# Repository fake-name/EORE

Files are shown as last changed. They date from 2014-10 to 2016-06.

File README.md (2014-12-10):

EORE
====

Era of Reionization Experiment

This is the hardware designs for the RF and backend components of a radio-telescope intended to look at the heavily [red-shifted](http://en.wikipedia.org/wiki/Redshift) [21 CM hydrogen line](http://en.wikipedia.org/wiki/Reionization#21-cm_line).  

While the normal 21 cm line is ~1420 MHz, this experiment is targeting the 50-250 MHz spectrum, which is where the 21 cm line from the era of reionization has been red-shifted to. 

Current topology is to use a SignalHound [BB60C](https://www.signalhound.com/products/bb60c/) spectrum analyser for the backend receiver (though my [API wrapper](https://github.com/fake-name/pySignalHound)), while the boards in this repository are front-end amplifiers and various components for tracking local oscillator drift, antenna characterization and so forth.

RF System hardware API documentation is [here](http://fake-name.github.io/EORE/doc/)

The eventual system will involve a great many separate nodes spread around the globe, all acting as a large-scale array.

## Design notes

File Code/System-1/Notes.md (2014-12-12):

I began to ask this question about the scheduling system on StackExchange, and partway through the writeup, I basically realised I was discussing the differences between cooperative multitasking and pre-emptive multitasking.

Since a single thread failing will tank the whole process, I've decided on a cooperative approach. 

###Approaches for handling complex scheduling requirements in a system involving many separate processes?

I'm working on designing a scheduling system that has to manage some complex, partially synchronous control state across a system that has a great many independent processes (it's a radio-telescope data-acquisition system, actually).

Basically, it requires a number of modules be cycled through a number of distinct steps on a repeating basis. 

 - Acquiring data (~30 minutes):
    - There are multiple separate processes that handle stream processing and write data out to file
    - Runs in a chunked basis, in ~30 second spans, which are challenging to interrupt.
 - Hardware calibration (short)
 - Antenna calibrarion (also short)
 - Other assorted housekeeping (pointing, etc...).

The critical thing is that I have to interrupt the main acquisition to perform calibration, and I'm trying to determine what the best approach to use for the system topology is.

 - Bottom-up scheduling:
    - Processes manage their own internal state, and yield flow back to a simple global loop periodically.
    - Effectively cooperative multitasking
 - Top-down scheduling:
    - State is managed in a global

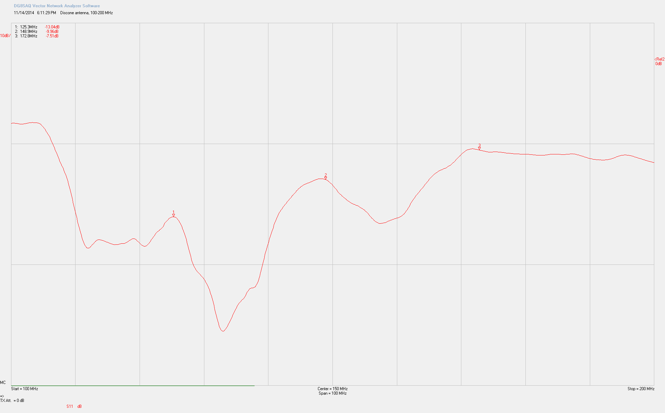
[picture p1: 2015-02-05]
Code/Prototypes/SWR Sweeper/SWR Sweep - Antenna - 100-200 Mhz, VNWA.png

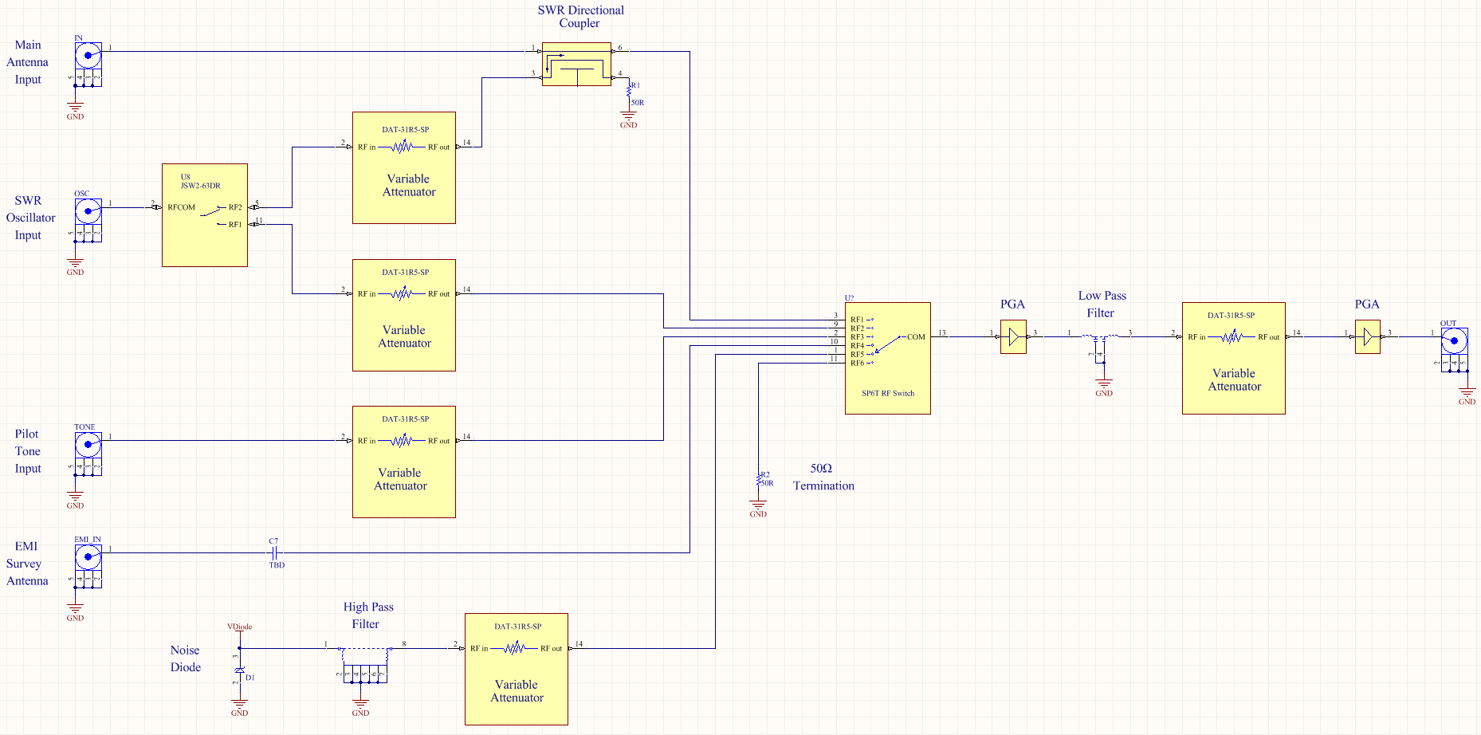
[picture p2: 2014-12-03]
PCBs/EORE R4 Diagram/EORE R4 Diagram.png

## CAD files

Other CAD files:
PCBs/Tigger RF Synthesizer & control module/RF Oscillator - R4/Rf Can 2.DWG
PCBs/Tigger RF Synthesizer & control module/RF Oscillator - R4/Rf Can 1.DWG
PCBs/Tigger RF Synthesizer & control module/RF Oscillator - R4/Draw1.SLDDRW

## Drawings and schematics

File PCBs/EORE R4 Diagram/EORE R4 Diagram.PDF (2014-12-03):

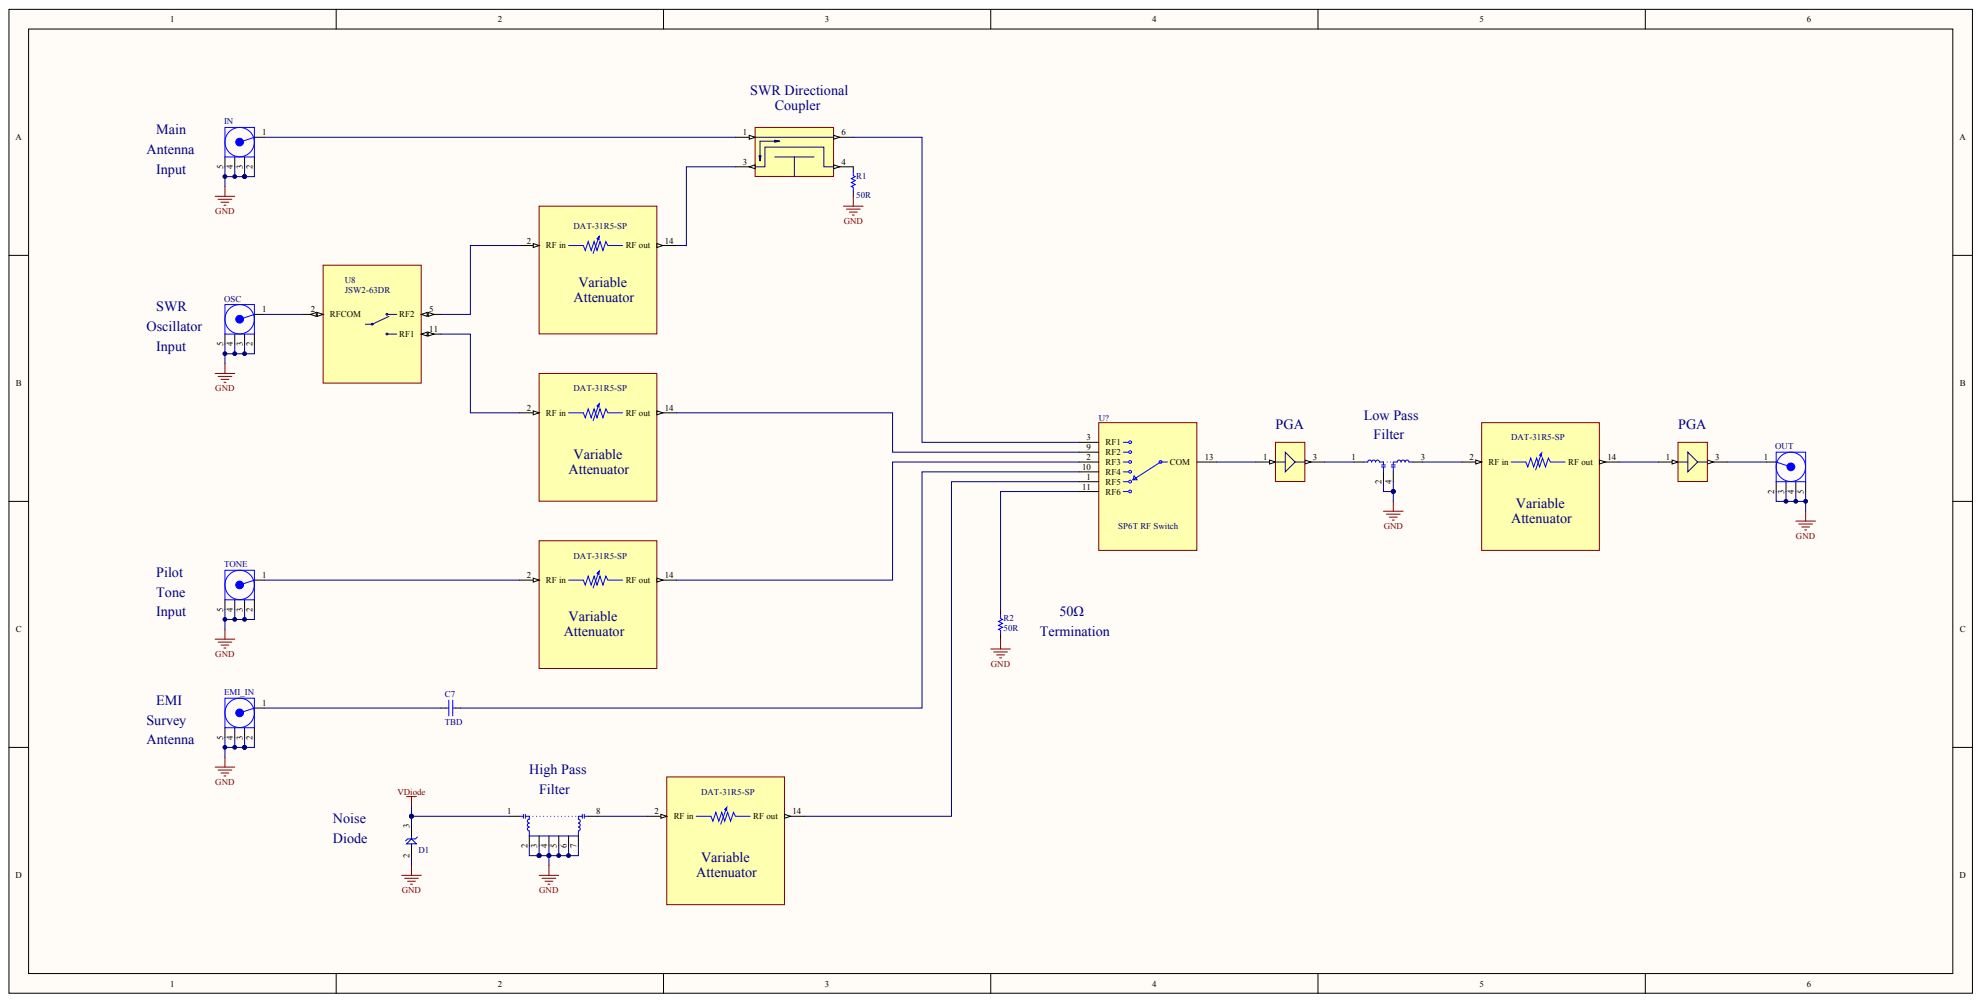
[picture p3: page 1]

RF3 2
RF4 10
RF5 1
RF6 11

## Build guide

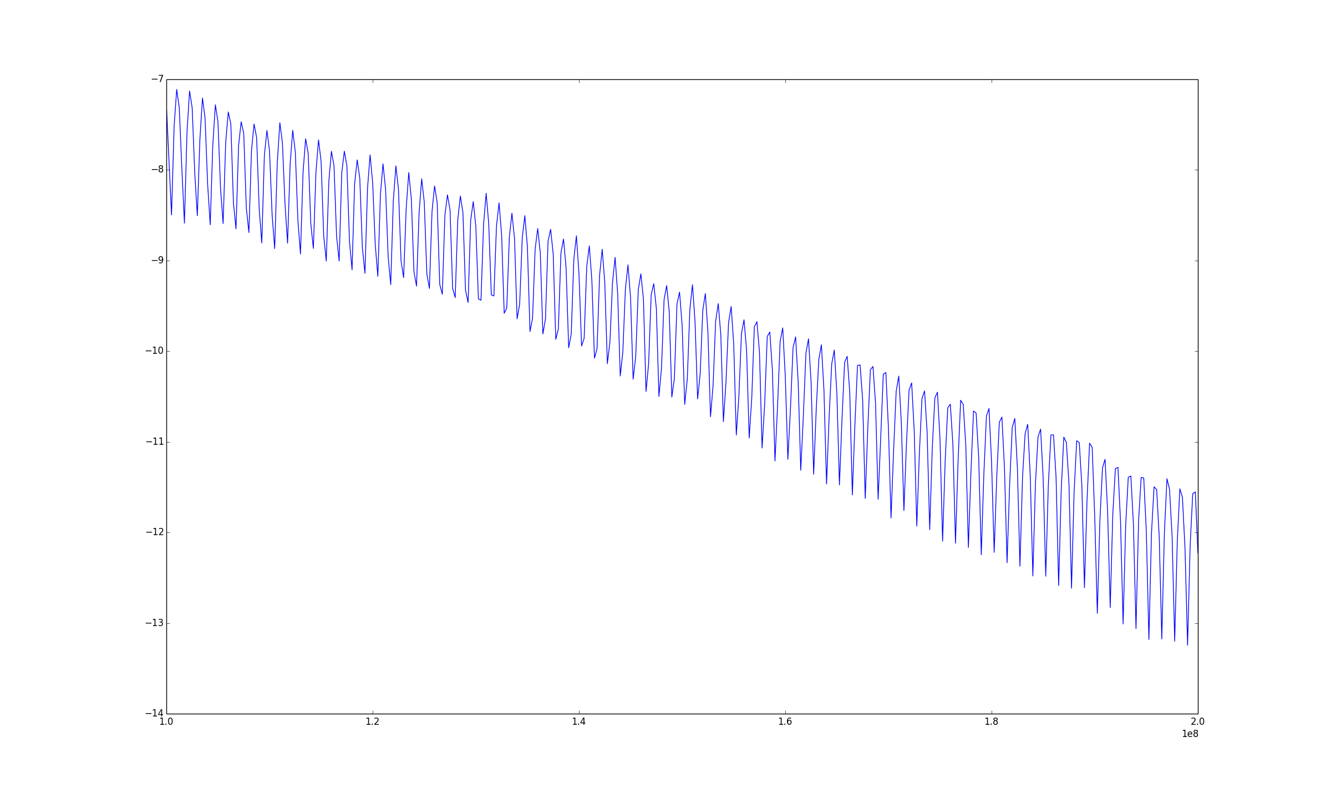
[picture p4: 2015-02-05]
Code/Prototypes/SWR Sweeper/SWR Sweep - Open input 100-200 Mhz, 250KHz steps.png

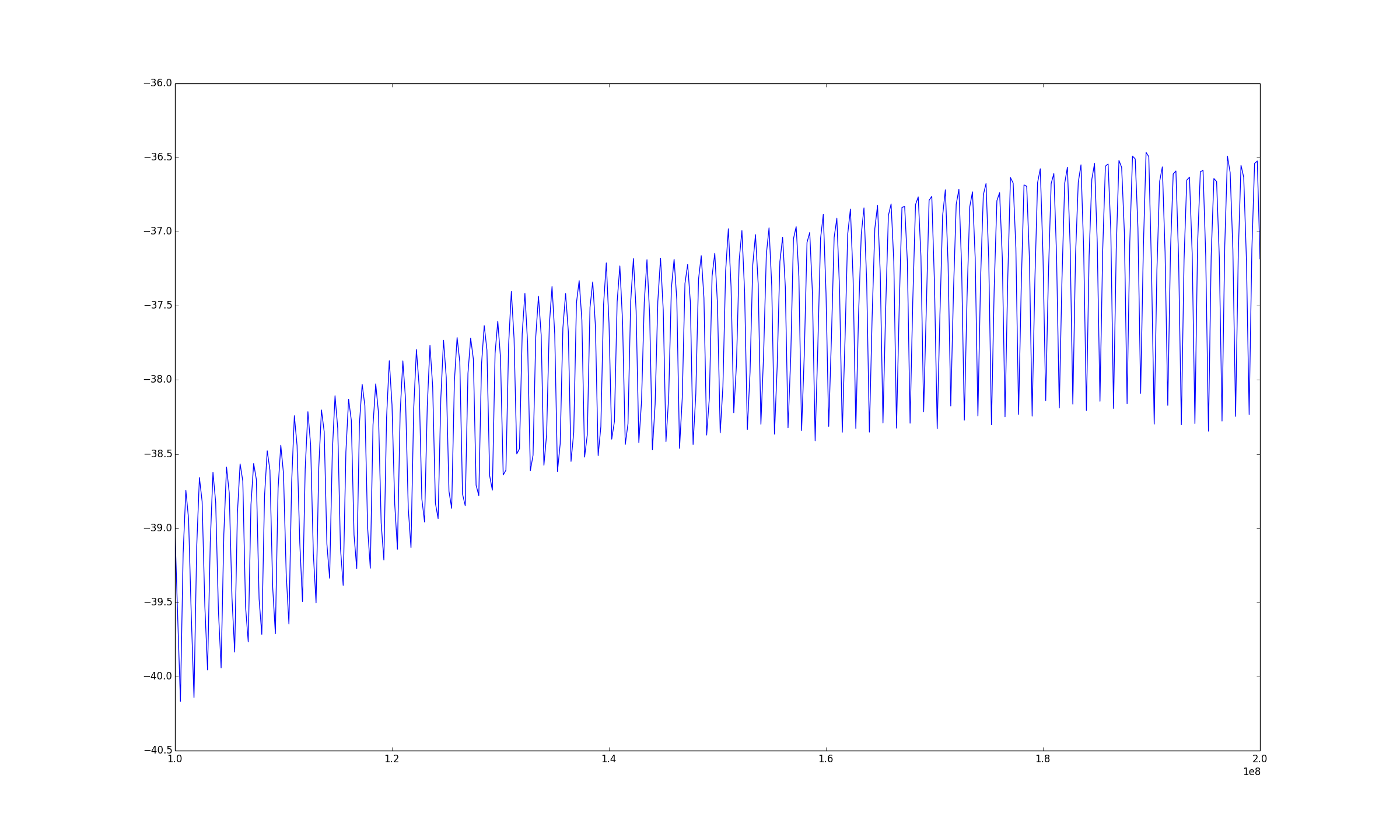
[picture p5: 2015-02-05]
Code/Prototypes/SWR Sweeper/SWR Sweep - Terminated input 100-200 Mhz, 250KHz steps.png

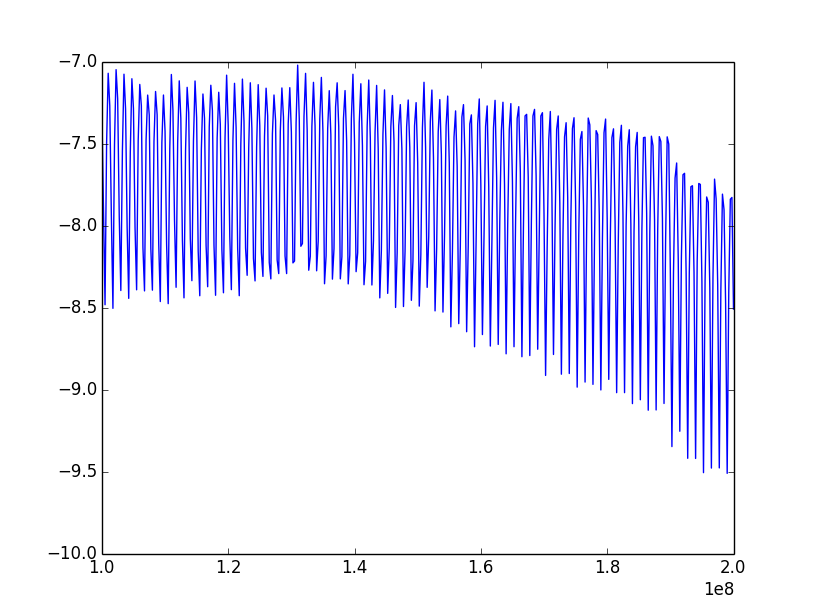
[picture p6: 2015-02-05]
Code/Prototypes/SWR Sweeper/SWR Sweep - Shorted input 100-200 Mhz, 250KHz steps.png

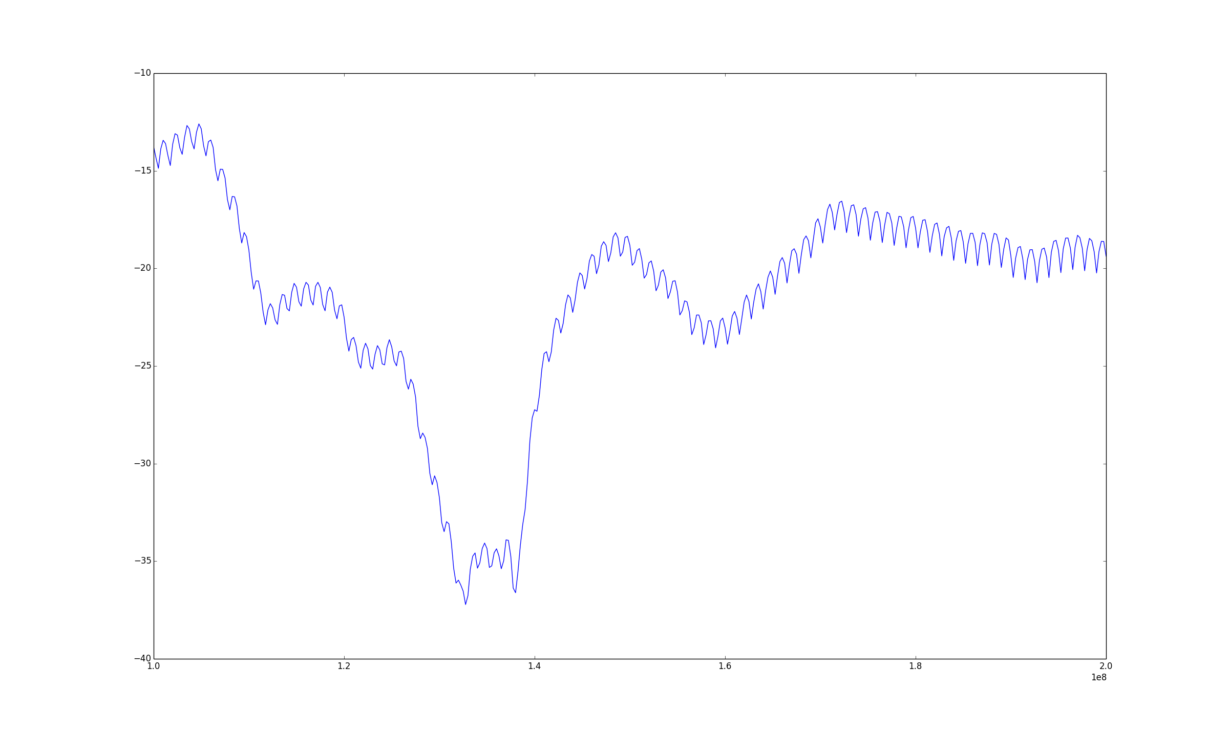
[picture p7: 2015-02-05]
Code/Prototypes/SWR Sweeper/SWR Sweep - Antenna - 100-200 Mhz, 250KHz steps.png

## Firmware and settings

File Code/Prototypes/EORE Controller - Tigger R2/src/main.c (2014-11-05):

/**
 * \file
 *
 * \brief Empty user application template
 *
 */

/**
 * \mainpage User Application template doxygen documentation
 *
 * \par Empty user application template
 *
 * Bare minimum empty user application template
 *
 * \par Content
 *
 * -# Include the ASF header files (through asf.h)
 * -# Minimal main function that starts with a call to board_init()
 * -# "Insert application code here" comment
 *
 */

/*
 * Include header files for all drivers that have been imported from
 * Atmel Software Framework (ASF).
 */
 #include <asf.h>
 #include <string.h>


#define DELAY_INTERVAL   250
#define TWI_SPEED        400000

void setup(void);
void send_led_command(uint8_t devAddr, uint8_t led, uint8_t brightness);


void setup(void)
{

	board_init();
	sysclk_init();
	ioport_init();
	wdt_disable(WDT);


	/* =============== UART1 =============== */ //(UART0 is defined but not UART1)
	#define PINS_DEVICE_TWI          (PIO_PA4A_TWCK0 | PIO_PA3A_TWD0)
	#define PINS_DEVICE_TWI_FLAGS    (PIO_PERIPH_A | PIO_DEFAULT)
	#define PINS_DEVICE_TWI_MASK     (PIO_PA4A_TWCK0 | PIO_PA3A_TWD0)
	#define PINS_DEVICE_TWI_PIO      PIOA
	#define PINS_DEVICE_TWI_ID       ID_PIOA
	#define PINS_DEVICE_TWI_TYPE     PIO_PERIPH_A
	#define PINS_DEVICE_TWI_ATTR     PIO_DEFAULT


	pio_configure_pin(PIO_PA3A_TWD0,  PIO_TYPE_PIO_PERIPH_A);
	pio_configure_pin(PIO_PA4A_TWCK0, PIO_TYPE_PIO_PERIPH_A);

	pio_configure(PINS_DEVICE_TWI_PIO, PINS_DEVICE_TWI_TYPE, PINS_DEVICE_TWI_MASK, PINS_DEVICE_TWI_ATTR);

	sysclk_enable_peripheral_clock(ID_TWI0);
	sysclk_enable_peripheral_clock(PINS_DEVICE_TWI_ID);
	sysclk_enable_peripheral_clock(ID_PIOB);


	twi_options_t conf;

	conf.master_clk = sysclk_get_cpu_hz();
	conf.speed = TWI_SPEED;
	conf.chip = 0;
	conf.smbus = 0;


	twi_master_init(DEVICE_TWI, &conf);

	ioport_set_pin_dir(LED_1, IOPORT_DIR_OUTPUT);
	ioport_set_pin_dir(LED_2, IOPORT_DIR_OUTPUT);
	ioport_set_pin_dir(LED_3, IOPORT_DIR_OUTPUT);
	ioport_set_pin_dir(LED_4, IOPORT_DIR_OUTPUT);

	// ioport_set_pin_level(LED_DRIVER_RESET, 1);
	// ioport_set_pin_dir(LED_DRIVER_RESET, IOPORT_DIR_OUTPUT);


	// // SoftI2CInit();
	// ioport_set_pin_level(LED_DRIVER_RESET, 0);
	// delay_ms(5);
	// ioport_set_pin_level(LED_DRIVER_RESET, 1);






}


void send_led_command(uint8_t devAddr, uint8_t led, uint8_t brightness)
{
	twi_packet_t packet;
	volatile uint8_t status;

	/* Data to send */
	packet.buffer = &brightness;
	/* Data length */
	packet.length = 1;
	/* Slave chip address */
	packet.chip = (uint32_t) devAddr >> 1;  // Device address must be >> by one, since apparently the driver injects the read/write flag internally
	/* Internal chip address */
	packet.addr[0] = led;
	packet.addr[1] = 0;
	packet.addr[2] = 0;
	/* Address length */
	packet.addr_length = 1;

	/* Perform a master write access */
	status = twi_master_write(TWI0, &packet);

	// if (status == TWI_SUCCESS)
	// {
	// 	ioport_toggle_pin_level(LED_6);
	// }
	// else
	// {
	// 	ioport_toggle_pin_level(LED_5);
	// }

}

int main (void)
{
	setup();

	uint8_t dir = 0;
	uint8_t brightness = 0;
	while (1)
	{



		// for (uint8_t led = 0; led < 16; led += 1)
		// {
		// 	send_led_command(DRV_1_ADDR, led, brightness);
		// 	send_led_command(DRV_2_ADDR, led, brightness);
		// 	send_led_command(DRV_3_ADDR, led, brightness);
		// 	send_led_command(DRV_4_ADDR, led, brightness);
		// }
		// // Spin
		// ioport_set_pin_level(LED_1, 1);
		// delay_ms(DELAY_INTERVAL);
		// ioport_set_pin_level(LED_1, 0);

		// if (brightness == 0xFF)
		// {
		// 	dir = 1;
		// }
		// else if (brightness == 0x00)
		// {
		// 	dir = 0;
		// }

		// if (dir == 0)
		// {
		// 	brightness += 1;
		// }
		// else if (dir == 1)
		// {
		// 	brightness -= 1;
		// }


		ioport_set_pin_level(LED_1, 1);
		delay_ms(DELAY_INTERVAL);
		ioport_set_pin_level(LED_1, 0);

		ioport_set_pin_level(LED_2, 1);
		delay_ms(DELAY_INTERVAL);
		ioport_set_pin_level(LED_2, 0);

		ioport_set_pin_level(LED_3, 1);
		delay_ms(DELAY_INTERVAL);
		ioport_set_pin_level(LED_3, 0);

		ioport_set_pin_level(LED_4, 1);
		delay_ms(DELAY_INTERVAL);
		ioport_set_pin_level(LED_4, 0);


	}
	// Insert application code here, after the board has been initialized.
}

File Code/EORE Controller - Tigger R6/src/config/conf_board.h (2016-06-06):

/**
 * \file
 *
 * \brief User board configuration template
 *
 */

#ifndef CONF_BOARD_H
#define CONF_BOARD_H

#define BOARD_FREQ_SLCK_XTAL 32768
#define BOARD_FREQ_SLCK_BYPASS BOARD_FREQ_SLCK_XTAL

#define BOARD_FREQ_MAINCK_XTAL 12000000
#define BOARD_FREQ_MAINCK_BYPASS BOARD_FREQ_MAINCK_XTAL

#define BOARD_OSC_STARTUP_US   15625


// Pin definitions
#define LED_1           IOPORT_CREATE_PIN(PIOA, 27)
#define LED_2           IOPORT_CREATE_PIN(PIOA, 11)
#define LED_3           IOPORT_CREATE_PIN(PIOA, 26)
#define LED_4           IOPORT_CREATE_PIN(PIOA, 12)

#define HEATER_ON       IOPORT_CREATE_PIN(PIOA, 2)

#define VCO_ON          IOPORT_CREATE_PIN(PIOA, 20)
//#define HEATER_OLD    IOPORT_CREATE_PIN(PIOA,  5)
#define OSC_EN          IOPORT_CREATE_PIN(PIOA,  9)
#define NOISE_DIODE_PS  IOPORT_CREATE_PIN(PIOB,  2)
#define VCO_SWEEPER_PS  IOPORT_CREATE_PIN(PIOA,  0)

#define CS_1            IOPORT_CREATE_PIN(PIOB,  3)
#define CS_2            IOPORT_CREATE_PIN(PIOA, 17)
#define CS_3            IOPORT_CREATE_PIN(PIOA, 18)
#define CS_4            IOPORT_CREATE_PIN(PIOA, 19)
#define CS_5            IOPORT_CREATE_PIN(PIOA, 16)
#define CS_6            IOPORT_CREATE_PIN(PIOA, 15)
#define CS_OSC_ATTEN    IOPORT_CREATE_PIN(PIOA, 10)   // also known as "CS7"
#define CS_SWEEP_ATTEN  IOPORT_CREATE_PIN(PIOA,  6)   // also known as "CS8"

//#define CS_SW           IOPORT_CREATE_PIN(PIOA, 18)

#define MOSI            IOPORT_CREATE_PIN(PIOA, 13)
#define SCK             IOPORT_CREATE_PIN(PIOA, 14)

//#define SWITCH_2        IOPORT_CREATE_PIN(PIOB, 1)
//#define SWITCH_3        IOPORT_CREATE_PIN(PIOB, 2)
//#define SWITCH_4        IOPORT_CREATE_PIN(PIOB, 3)

// SI57x TWI port.
#define DEVICE_SCL      IOPORT_CREATE_PIN(PIOA, 4)
#define DEVICE_SDA      IOPORT_CREATE_PIN(PIOA, 3)
#define DEVICE_TWI      TWI0

// Temperature sensors get their own TWI module.
#define TEMP_SENSOR_SCL      IOPORT_CREATE_PIN(PIOB, 1)
#define TEMP_SENSOR_SDA      IOPORT_CREATE_PIN(PIOB, 0)
#define TEMP_SENSOR_TWI      TWI2


#define DRV_1_ADDR  (0xA0 | 0 << 1)
#define DRV_2_ADDR  (0xA0 | 1 << 1)
#define DRV_3_ADDR  (0xA0 | 2 << 1)
#define DRV_4_ADDR  (0xA0 | 3 << 1)


/* =============== TWI1 =============== */
#define PINS_DEVICE_TWI          (PIO_PA4A_TWCK0 | PIO_PA3A_TWD0)
#define PINS_DEVICE_TWI_FLAGS    (PIO_PERIPH_A | PIO_DEFAULT)
#define PINS_DEVICE_TWI_MASK     (PIO_PA4A_TWCK0 | PIO_PA3A_TWD0)
#define PINS_DEVICE_TWI_PIO      PIOA
#define PINS_DEVICE_TWI_ID       ID_PIOA
#define PINS_DEVICE_TWI_TYPE     PIO_PERIPH_A
#define PINS_DEVICE_TWI_ATTR     PIO_DEFAULT


/* =============== Debug UART =============== */
#define DEBUG_UART                 (Usart*)UART3
#define DEBUG_UART_ID              ID_UART3
#define DEBUG_UART_BAUDRATE        115200
#define DEBUG_UART_MODE            UART_MR_PAR_NO
#define DEBUG_UART_CHAR_LENGTH     8
#define DEBUG_UART_PARITY          UART_MR_PAR_NO
#define DEBUG_UART_STOP_BIT        false

#define DEBUG_UART_PIN_TX         IOPORT_CREATE_PIN(PIOB, 11)
#define DEBUG_UART_PIN_RX         IOPORT_CREATE_PIN(PIOB, 10)

#define DEBUG_UART_IRQ            UART3_IRQn
#define DEBUG_UART_ISR_HANDLER    UART3_Handler



#endif // CONF_BOARD_H

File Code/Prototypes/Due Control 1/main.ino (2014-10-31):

#define SI570_DEBUG

#include <Wire.h>
#include <stdlib.h>
#include "Si570.h"

Si570 *vfo;


#define SW_1 		44
#define SW_2 		30
#define SW_3 		32

#define DATA 		34
#define LATCH_3 	36
#define CLK 		38
#define LATCH_2 	40
#define LATCH_1 	42

uint8_t pins[] = {30, 32, 34, 36, 38, 40, 42, 44};
uint8_t cnt;



#define PACKET_HEADER 0x5D
#define WRITE_ATTEN_1 0xAA
#define WRITE_ATTEN_2 0xAB
#define WRITE_ATTEN_3 0xAC
#define WRITE_SWITCH  0x0C
#define WRITE_FREQ    0xC0


typedef enum
{
	NO_PACKET,
	WAIT_COMMAND,

	WAIT_DATA_1,
	WAIT_DATA_2,
	WAIT_DATA_3,
	WAIT_DATA_4,
	WAIT_CHECKSUM,

	PACKET_VALID
} sysState;




typedef union UnionU32_t
{
	uint8_t  bytes[4];
	uint32_t value;
} unionU32_t;

typedef struct
{
	uint8_t command;
	unionU32_t value;
} command_packet;


volatile uint8_t checksum = 0;

volatile command_packet packet = {0, 0};
volatile sysState state = NO_PACKET;


#define _BV(bit) (1 << (bit))

void writeAtten(uint8_t which, uint8_t atten)
{
	uint8_t cs_pin;
	switch (which)
	{
		case 0:
			cs_pin = LATCH_1;
			break;
		case 1:
			cs_pin = LATCH_2;
			break;
		case 2:
			cs_pin = LATCH_3;
			break;
		default:
			return;
	}

	if (atten >= 64)
	{
		return;
	}

	for (uint8_t i = 0; i < 6; i += 1)
	{
		if (atten & _BV(5-i))
			digitalWrite(DATA, 1);
		else
			digitalWrite(DATA, 0);
		delayMicroseconds(2);
		digitalWrite(CLK, 1);
		delayMicroseconds(2);
		digitalWrite(CLK, 0);
		delayMicroseconds(2);


	}

	digitalWrite(DATA, 0);
	digitalWrite(cs_pin, 1);
	delayMicroseconds(2);
	digitalWrite(cs_pin, 0);



}

void writeSwitch(uint8_t val)
{
	// SO input 1 of the switch is the *MOST* significant bit. Wat?
	if (val & _BV(0))
		digitalWrite(SW_3, 1);
	else
		digitalWrite(SW_3, 0);

	if (val & _BV(1))
		digitalWrite(SW_2, 1);
	else
		digitalWrite(SW_2, 0);

	if (val & _BV(2))
		digitalWrite(SW_1, 1);
	else
		digitalWrite(SW_1, 0);

}







void process_packet(volatile command_packet *pkt)
{

	switch (pkt->command)
	{
		case WRITE_ATTEN_1:
			Serial.print("Atten Set 1 ");
			Serial.println(pkt->value.value);
			writeAtten(0, (uint8_t) pkt->value.value);
			break;

		case WRITE_ATTEN_2:
			Serial.print("Atten Set 2 ");
			Serial.println(pkt->value.value);
			writeAtten(1, (uint8_t) pkt->value.value);
			break;

		case WRITE_ATTEN_3:
			Serial.print("Atten Set 3 ");
			Serial.println(pkt->value.value);
			writeAtten(2, (uint8_t) pkt->value.value);
			break;


		case WRITE_SWITCH:
			Serial.print("Switch Set ");
			Serial.println(pkt->value.value);
			writeSwitch((uint8_t) pkt->value.value);
			break;

		case WRITE_FREQ:
			if (pkt->value.value < 10e6 | pkt->value.value > 810e6 )
			{
				Serial.print("ERROR: Invalid Frequency: ");
				Serial.println(pkt->value.value);
			}
			else
			{
				vfo->setFrequency(pkt->value.value);
				Serial.print("OK: Freq Set: ");
				Serial.println(pkt->value.value);
			}
			break;

		default:
			Serial.println("Error! Unknown command!");
			break;
	}


}


void parse(uint8_t dataByte)
{
	switch (state)
	{
		case NO_PACKET:
			if (dataByte == PACKET_HEADER)
			{
				state = WAIT_COMMAND;
				checksum += dataByte;
			}
			break;

		case WAIT_COMMAND:
			packet.command = dataByte;
			state = WAIT_DATA_1;
			checksum += dataByte;
			break;

		case WAIT_DATA_1:

			packet.value.bytes[0] = dataByte;
			state = WAIT_DATA_2;
			checksum += dataByte;
			break;
		case WAIT_DATA_2:

			packet.value.bytes[1] = dataByte;
			state = WAIT_DATA_3;
			checksum += dataByte;
			break;
		case WAIT_DATA_3:

			packet.value.bytes[2] = dataByte;
			state = WAIT_DATA_4;
			checksum += dataByte;
			break;
		case WAIT_DATA_4:

			packet.value.bytes[3] = dataByte;
			state = WAIT_CHECKSUM;
			checksum += dataByte;
			break;

		case WAIT_CHECKSUM:

			if (dataByte ==  checksum)
			{
				state = PACKET_VALID;
				process_packet(&packet);
			}
			else
			{
				Serial.println("Invalid checksum!");
				Serial.print("Should be ");
				Serial.print(checksum);
				Serial.print(" received ");
				Serial.println(dataByte);
			}
			// Falls through to default (intentionally)!
		default:
			Serial.print("Rx Complete");
			state = NO_PACKET;
			checksum = 0;
			break;
	}

}




void setup(){}


void loop()
{

	for (uint8_t x = 0; x < sizeof(pins); x += 1)
	{
		pinMode(pins[x], OUTPUT);
		digitalWrite(pins[x], 0);
	}

	Serial.begin(115200);


	Serial.println("Device init...");
	vfo = new Si570(SI570_I2C_ADDRESS, 56.320e6);

	if (vfo->status == SI570_ERROR) {
		// The Si570 is unreachable. Show an error for 3 seconds and continue.
		Serial.println("Si570 comm error");
		delay(3000);
	}


	// This will print some debugging info to the serial console.
	vfo->debugSi570();


	#define DELAY_TIME 200



	vfo->setFrequency(100E6);


	while(1)
	{
		if (Serial.available())
		{
			uint8_t ser = Serial.read();
			parse(ser);
		}
	}

}

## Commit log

2014-10-09 Initial push of sources from SVN.
    [Amplifier.SchDoc, Attenuator.SchDoc, Directional Coupler.SchDoc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]
2014-10-09 Adding test-board control sources.
2014-10-10 Ordered the R3/4 PCBs. Minor testing code stuff.
    [EORE Integrated System - R3.PrjPcb, Main.PcbDoc, RF Oscillator - R4.PrjPcb]
2014-10-14 Added the ability to control the SI570 over the serial interface. Also, the corresponding python wrapper for talking to the oscillator board.
    [Si570.cpp, control.py, outCon.ino]
2014-10-16 Aggregated control systems onto the due board.
2014-10-24 Next RF synthesizer board. This one has a mixer-based VCO driven sweep oscillator, for faster VSWR sweeps.
    [Attenuator.SchDoc, Main.PcbDoc, Main.SchDoc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]
2014-10-25 Initial prototype SWR sweeper.
2014-10-29 More work on the EORE boards.
    [Main.PcbDoc, Programming Interface and Power.SchDoc, RF Oscillator - R5.PrjPcb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]
2014-10-30 There's a bug somewhere in the Si570 library that is causing the output of the oscillator to be incorrect at ~200 Mhz. Arrrgh.
    [Si570.cpp, controlApi.py, takeSweeps.py]
2014-10-31 Fixed bizarre rounding bug in the Si570 control code. Fuck you ridiculously confusing code.
    [Si570.cpp, main.ino]
2014-10-31 Testing the Si570 output stability.
    [Si570.cpp, controlApi.py, siCalc.py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]
2014-10-31 Next EORE board rev.
    [Attenuator.SchDoc, EORE Integrated System - R4.PrjPcb, Main.PcbDoc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]
2014-11-05 did the assembly of the new EORE Eeyore and Tigger boards. Some updates/minor changes to the drawings from the assembly process.
    [Programming Interface and Power.SchDoc, RF Oscillator - R4.PrjPcb, USB Interface.SchDoc]
2014-11-05 Initial test-code for the EORE Tigger control board. It's mostly stolen from an earlier project. It just flashes some LEDs at this point, but that means all the board-init crap is working. Whooo?
2014-11-05 Ignore build files for the ARM stuff.
2014-11-06 Entirely switched project over to C++ so I can ~~steal~~ reuse arduino libraries. Got some basic printf functions working. Spent a while dicking about with header file.
2014-11-06 I2C reads are working, writing is a bit broken. Progress!
    [Main.PcbDoc]
2014-11-07 All peripherals now seem to work. At this point, the only things remaining are to implement the interrupt-driven serial rx buffer, and hook up the command parser. I have RX interrupts working, but ri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
    [Main.PcbDoc, Main.SchDoc, USB Interface.SchDoc]
2014-11-08 Controller is actually functional, parser is hooked up. There's some issues somewhere still, not sure if it's real or just idiocy in my testing practices for the amps.
    [EORE Integrated System - R4.PrjPcb, Main.PcbDoc, Main.SchDoc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]
2014-11-13 Improved footprints for the all the small SMT parts. Better silkscreen pin-1 markings, larger pads for the SP6T switch so it can hopefully be soldered and/or reflowed more easily in the future.
    [Main.PcbDoc]
2014-11-14 Board fixes.
    [EORE Integrated System - R2.PrjPcb, Main.PcbDoc, RF Oscillator - R4.PrjPcb]
2014-11-15 More work on SWR sweeper. Improvements on the EORE interface library. Updated readme.
    [Main.PcbDoc]
2014-11-15 Added high-pass filter to noise diode, which should (hopefully) remove the extremely high amplitude low-frequency output from the noise-diode, that is causing issues saturating the IF stage of the si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
    [Main.PcbDoc, Main.SchDoc, Noise Diode.SchDoc]
2014-11-19 Wound up editing the wrong board (I was updating the R3 board files, not the R4 version. Swapped the files around to fix.
    [EORE Integrated System - R3.PrjPcb, EORE Integrated System - R4.PrjPcb, Main.PcbDoc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]
2014-11-20 New board ordering.
    [EORE Integrated System - R4.PrjPcb, Main.PcbDoc, Main.SchDoc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]
2014-11-21 Temp sensing now works on the Tigger controller board.
    [RF Oscillator - R5.PrjPcb]
2014-11-22 PWM output now works, and is tested. Cleaned up the code structure a bit too.
    [Main.PcbDoc, USB Interface.SchDoc]
2014-11-25 Thermal regulator now thermally regulates. PID loop will need tuning for the eventual system's thermal characteristics, but it's functional. General cleanup, moved the init functions into the proper 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
2014-11-25 Oh god stupid issues with the PCBs. Fixed the fucked up paste-mask for the EMI cans on the RF osc boards. Ordered the paste-masks.
    [EORE Integrated System - R4.PrjPcb, Main.PcbDoc, RF Oscillator - R5.PrjPcb]
2014-11-25 Added command parser hooks for the PID temperature controller.
2014-12-03 System topology diagrams
    [EORE R4 Diagram.PrjPcb, Main.SchDoc]
2014-12-03 Forgot to junction across the R6 osc board.
    [Attenuator.SchDoc, Main.PcbDoc, Main.SchDoc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]
2014-12-03 Improving the control parser.
    [EORE Integrated System - R4.PrjPcb, RF Oscillator - R5.PrjPcb]
2015-01-09 Split EORE source off for the new board.
    [Programming Interface and Power.SchDoc, RF Oscillator - R5.PrjPcb, USB Interface.SchDoc]
2015-01-21 One spectacularly stupid error in the oscillator/controller board (op amp inputs reversed). WTF was I thinking?
    DAC now works, and the VCO sweeper seems to work quite well.
    [Main.PcbDoc, Main.SchDoc, Sweep Oscillator.SchDoc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]
2015-01-22 Frequency chirp system implemented, I2C interface code abstracted out to a separate driver file.
    [Main.PcbDoc, Main.SchDoc, Sweep Oscillator.SchDoc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]
2015-01-23 Well, I broke something in the I2C library somehow. No idea /what/, but it's deadlocking again.
    [Main.PcbDoc]
2015-01-23 Cross-merge from Broken_I2C Branch.
    [Main.PcbDoc]
2015-01-23 "Broken" I2C wound up being plain-old PEBKAC. One of the I2C devices had apparently crashed (or something), and had tied the bus low. Reset the whole PCB, and it started working fine again.
    DERP.
    [control.py, main.cpp, print.cpp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]
2015-01-24 Patch, patch, patch, patch. Switches, attenuators should work (MOSI/SCK are valid, in any case). Fixed PEBKAC in I2C drivers (write function was calling master_read(). Derp).
    [Main.PcbDoc]
2015-01-29 Minor board tweaks, Lots of hardware verification.
    [Main.PcbDoc]
2015-01-30 Doing the testy testy things.
    [Main.SchDoc]
2015-02-05 Changed to SPI DAC.
    [Main.PcbDoc, Main.SchDoc, Pilot Tone - Reference.SchDoc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]
2015-02-11 Added simple support for turning off he VCOs, bodged some little tiny MOSFETs onto the existing board to make it work.
    [Main.PcbDoc, Main.SchDoc]
2015-02-11 Polishing for ordering.
    [Main.PcbDoc, Sweep Oscillator.SchDoc, USB Interface.SchDoc]
2015-02-11 Next rev of boards ordered.
    [EORE Integrated System - R4.PrjPcb, Main.PcbDoc, RF Oscillator - R6.PrjPcb]
2015-02-11 Forgot to add the local PDU/DC-DC for power management.
    [EORE PDU - R1.PrjPcb, Main.SchDoc]
2015-02-12 Added proper response checks to the control interface system.
    [EORE Integrated System - R4.PrjPcb]
2015-02-13 Minor patching, convenience call to let you turn off the VCO without having to remember what does what.
    [Main.PcbDoc, USB Interface.SchDoc]
2015-02-17 I somehow managed to munge up some of the file locations for the EORE board. Whoops?
    [EORE Connector and Filtering.SchDoc, RF Oscillator - R6.PrjPcb]
2015-02-18 Whoops, wrong CS pin for one of the attenuators. Derp.
    [Main.PcbDoc]
2016-05-29 Update to AS7. Changed target device from SAM4N8A to SAM4N8B (not sure why that was wrong, did I make hardware changes before the last board-spin?).
2016-06-06 Created a new project set for the R6 EORE board, since it uses a bigger version of the arm MCU..
    [EORE Connector and Filtering.SchDoc]
